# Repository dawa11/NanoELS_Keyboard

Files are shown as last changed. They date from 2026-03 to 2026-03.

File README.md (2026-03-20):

# Custom Mechanical Keyboard for NanoELS H5

## 1. Project Overview

This project provides the design and instructions to build a custom mechanical keyboard specifically tailored for the **NanoELS H5**. The NanoELS H5 is an advanced Electronic Lead Screw (ELS) system.

For more information on the NanoELS H5, please visit the official documentation and source code:
[https://github.com/kachurovskiy/nanoels/tree/main/h5](https://github.com/kachurovskiy/nanoels/tree/main/h5)

This keyboard combines all the essential keys documented for the H5 onto a simple, robust switchplate using mechanical switches, providing tactile feedback and a dedicated interface for operating your machine.

Photo of the finished Switchplate

---

## 2. Bill of Materials (BOM) & Requirements

To complete this build, you will need the following components and tools:

### Components
* **1x Microcontroller:** Must have at least **15 GPIO pins** and be **5V tolerant**.
    * *Recommended:* Arduino Micro or a compatible clone.
* **42x Mechanical Keyboard Switches:** Cherry MX style or clones.
* **Wiring/Cabling:** Thin hook-up wire.

### Tools & Equipment
* **Soldering Iron**
* **3D Printer**

---

## 3. 3D Printed Parts & Printing Guidelines

You have several options for the 3D printed parts, depending on your printer setup and aesthetic preferences.

### Options

#### Switchplate
* **Grooves:** Features visual separation grooves between the different key groups. Ideal for single-color prints.
* **Multi Material:** Has a flat surface modeled as a diferrent material between the key groups, designed for multi-color printing.

#### Keycaps
* **Embedded:** The key legends (labels) are modeled into the surface of the keycap. For single-color printing.
* **Multi Material:** Flat, the key legends are modeled as a diferrent material so they can be printed with two colors. Ideal for multi-color printing of the legends or manual labeling.

### Printing Requirements
* **Switchplate:** Can be printed with a standard **0.4mm nozzle**.
* **Keycaps:** To ensure the embedded or multi-color legends are legible, these **must** be printed with a finer **0.2mm nozzle** (hotend).

---

## 4. Wiring & Schematic

After fitting the 42 switches into the switchplate, they must be wired in a matrix configuration. The following schematic shows how to solder the switches to create a **7 row x 6 column switch matrix**.

Wire the Switches as shown in the Wiring Diagrams.
First the Rows of the Matrix.
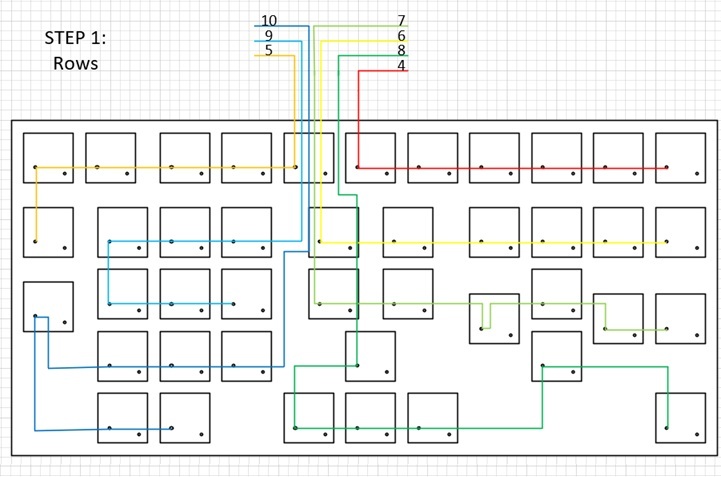
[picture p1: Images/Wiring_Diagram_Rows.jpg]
Wiring Diagram Rows


After that the Colums
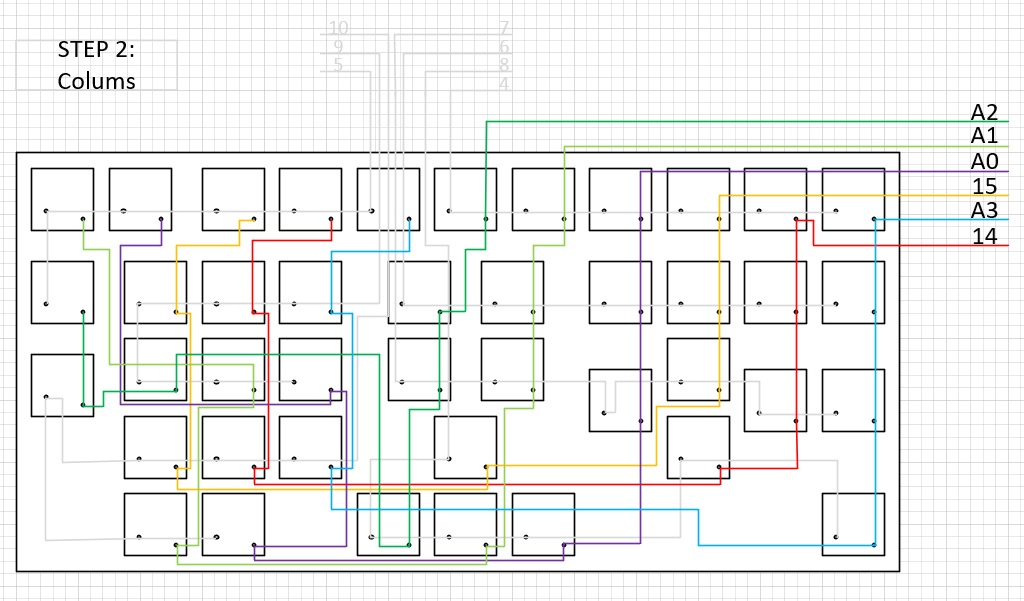
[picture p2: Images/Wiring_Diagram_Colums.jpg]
Wiring Diagram Rows


Finaly connect the wires to the specified PINs on the Microcontroller

This matrix is scanned by the microcontroller (e.g., Arduino Micro). The microcontroller translates the keypresses and sends the corresponding data to the NanoELS H5 controller via a **PS/2** interface.

### Controller Connection

To connect the keyboard to the NanoELS controller, use the following pinout:

| Arduino Pins | NanoELS PINS | Function |
| :--- | :--- | :--- |
| **VCC** | **5V** | Power Supply |
| **GND** | **GND** | Ground |
| **2** | **KEYC** | PS/2 Clock |
| **3** | **KEYD** | PS/2 Data |

---

## 5. Flashing the Controller

Download the Firmware **NanoELS-Keyboard.ino** from the Folder Source/NanoELS-Keyboard and FLash it to you Microcontroller with ArduinoIDE. After the flashing is completed you can open the Serial Monitor and look if the Arduino register every keypress.

---

## 6. Planned Improvements (Roadmap)

* **Handwheels:** Addition of mounting points for two incremental rotary encoders (handwheels) on the sides of the switchplate for precise X and Z axis control.

---

## 7. Known Bugs & Limitations

* **Unimplemented Keys:** The button corresponding to `Angle/RPM/Wifi` are currently non-functional.
* **STEP Buttons:** The `STEP +` and `STEP -` buttons currently perform the exact same function.
* **No Ghosting Protection:** The keyboard matrix does **not** include diodes. Pressing multiple keys simultaneously may lead to incorrect key detections ("ghosting"). **Only one key should be pressed at a time.**

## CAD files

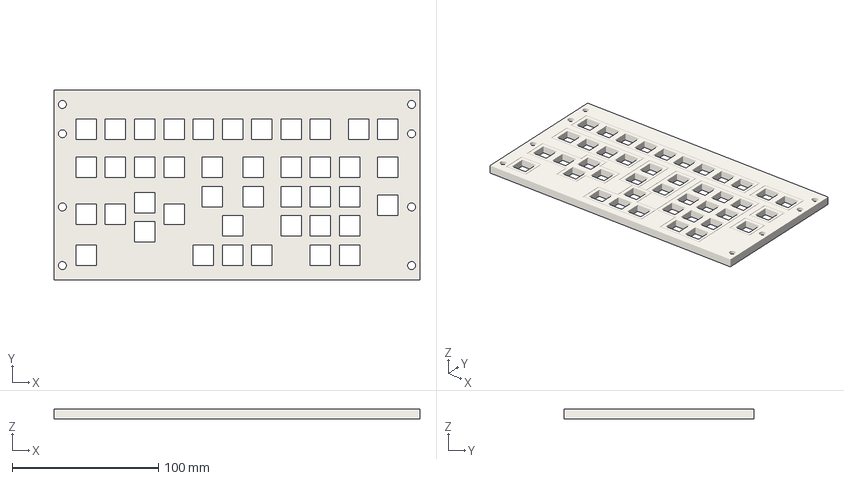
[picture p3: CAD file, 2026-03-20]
3D Files/Switchplate - grooves.3mf
250.0 x 130.0 x 7.00 mm

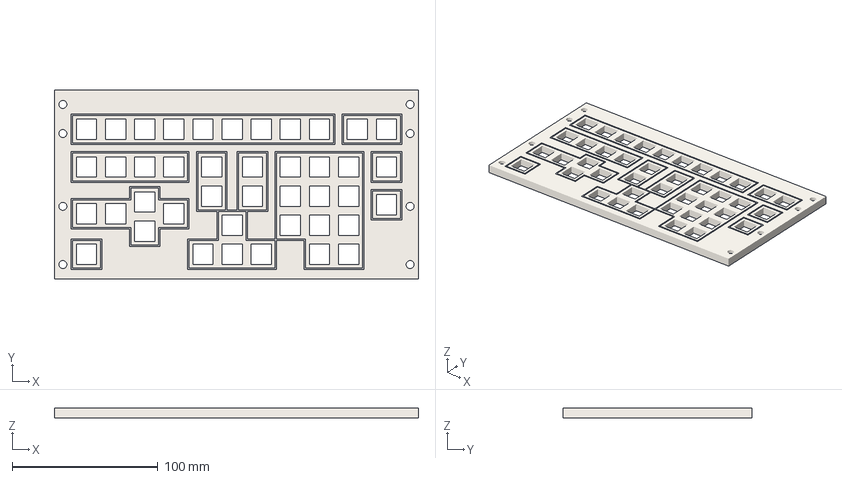
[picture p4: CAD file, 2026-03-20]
3D Files/Switchplate - Multi Material.3mf
250.0 x 130.0 x 7.00 mm
Körper1
Körper2
Körper3
Körper4
Körper5
Körper6
Körper7
Körper8
Körper9

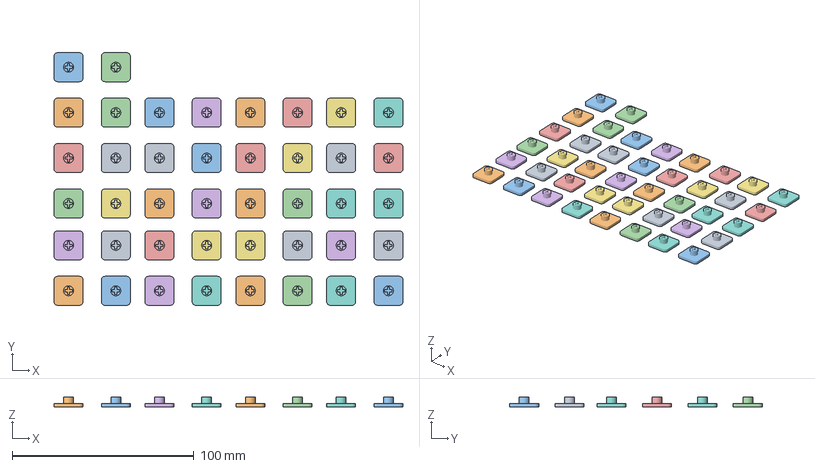
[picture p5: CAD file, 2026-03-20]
3D Files/Keycaps - embedded.3mf
192.0 x 139.0 x 5.60 mm
Körper10
Körper11
Körper12
Körper13
Körper14
Körper15
Körper16
Körper17
Körper18
Körper19
Körper2
Körper20
Körper21
Körper22
Körper23
Körper24
Körper25
Körper26
Körper27
Körper28
Körper29
Körper3
Körper30
Körper31
Körper32
Körper33
Körper34
Körper35
Körper36
Körper37
Körper38
Körper39
Körper4
Körper40
Körper41
Körper42
Körper5
Körper6
Körper7
Körper8
Körper9 x 2

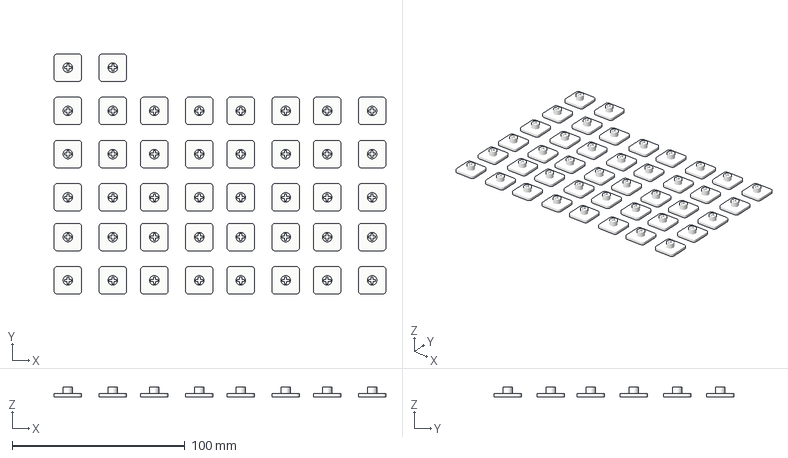
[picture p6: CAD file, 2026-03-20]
3D Files/Keycaps - Multi Material.3mf
192.0 x 139.0 x 5.60 mm
Körper1
Körper10
Körper100
Körper101
Körper102
Körper103
Körper104
Körper105
Körper106
Körper107
Körper108
Körper109
Körper11
Körper110
Körper111
Körper112
Körper113
Körper114
Körper115
Körper116
Körper117
Körper118
Körper119
Körper12
Körper120
Körper121
Körper122
Körper123
Körper124
Körper125
Körper126
Körper127
Körper128
Körper129
Körper13
Körper130
Körper131
Körper132
Körper133
Körper134
Körper135
Körper136
Körper137
Körper138
Körper139
Körper14
Körper140
Körper141
Körper142
Körper143
Körper144
Körper145
Körper146
Körper147
Körper148
Körper149
Körper15
Körper150
Körper151
Körper152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

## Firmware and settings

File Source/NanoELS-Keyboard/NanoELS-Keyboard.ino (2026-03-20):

#include <Keypad.h>
#include <ps2dev.h>

// PS/2 Pins: Clock an Pin 2, Data an Pin 3
PS2dev keyboard(2, 3);

const byte ROWS = 7; 
const byte COLS = 6; 

// Definition der Pins
byte rowPins[ROWS] = {4, 5, 6, 7, 8, 9, 10}; 
byte colPins[COLS] = {A3, 14, 15, A0, A1, A2}; 

// Tasten-Indizes für die Matrix
char keys[ROWS][COLS] = {
  {'q', 'w', 'e', 'r', 't', 'z'},   //F1, F2, F3, F4, F5, F6
  {'u', 'i', 'o', 'p', 'a', 'R'},   //F7, F8, F9, Enter, ESC, R
  {'Q', 'A', 'Z', 'D', '`', '+'},   //Q, A, Z, D, `, +
  {'C', 'S', 'X', 'W', '~', '-'},   //C, S, X, W, ~, -
  {'s', 'O', 'f', 'h', 'g', 'j'},   //Win, O, Up-Arrow, Left-Arrow, Down Arrow~, Right-Arrow
  {'7', '8', '9', '4', '5', '6'},   //7, 8, 9, 4, 5, 6
  {'1', '2', '3', '0', 'd', 'M'}    //1, 2, 3, 0, Backspace, M
};

Keypad keypad = Keypad(makeKeymap(keys), rowPins, colPins, ROWS, COLS);

void setup() {
  keyboard.keyboard_init();
  Serial.begin(9600);
}

// Zentrale Funktion zum Senden der PS/2 Befehle (Set 2)
void sendPS2(uint16_t scancode, bool pressed) {
  if (pressed) {
    if (scancode > 0xFF) keyboard.write(0xE0); // Extended-Präfix
    keyboard.write(scancode & 0xFF);           // Make-Code
  } else {
    if (scancode > 0xFF) keyboard.write(0xE0); // Extended-Präfix
    keyboard.write(0xF0);                      // Break-Code Präfix
    keyboard.write(scancode & 0xFF);           // Key-Code
  }
}

void loop() {
  // keypad.getKeys() füllt eine interne Liste mit allen Tasten, 
  // deren Status sich geändert hat.
  if (keypad.getKeys()) {
    // Wir nutzen hier 10 als Sicherheit (maximale Anzahl gleichzeitig erkannter Tasten)
    for (int i=0; i<10; i++) { 
      if (keypad.key[i].stateChanged) {
        bool isPressed = (keypad.key[i].kstate == PRESSED || keypad.key[i].kstate == HOLD);
        processKey(keypad.key[i].kchar, isPressed);
      }
    }
  }
}

void processKey(char key, bool pressed) {
  switch (key) {
    // Buchstaben
    case 'A': sendPS2(0x1C, pressed); Serial.println("A"); break;
    case 'W': sendPS2(0x1D, pressed); Serial.println("W"); break;
    case 'S': sendPS2(0x1B, pressed); Serial.println("S"); break;
    case 'D': sendPS2(0x23, pressed); Serial.println("D"); break;
    case 'R': sendPS2(0x2D, pressed); Serial.println("R"); break;
    case 'M': sendPS2(0x3A, pressed); Serial.println("M"); break;
    case 'X': sendPS2(0x22, pressed); Serial.println("X"); break;
    case 'Z': sendPS2(0x1A, pressed); Serial.println("Z"); break;
    case 'C': sendPS2(0x21, pressed); Serial.println("C"); break;
    case 'Q': sendPS2(0x15, pressed); Serial.println("Q"); break;
    case 'O': sendPS2(0x44, pressed); Serial.println("O"); break;

    // F-Tasten
    case 'q': sendPS2(0x05, pressed); Serial.println("F1"); break; // F1
    case 'w': sendPS2(0x06, pressed); Serial.println("F2"); break; // F2
    case 'e': sendPS2(0x04, pressed); Serial.println("F3"); break; // F3
    case 'r': sendPS2(0x0C, pressed); Serial.println("F4"); break; // F4
    case 't': sendPS2(0x03, pressed); Serial.println("F5"); break; // F5
    case 'z': sendPS2(0x0B, pressed); Serial.println("F6"); break; // F6
    case 'u': sendPS2(0x83, pressed); Serial.println("F7"); break; // F7
    case 'i': sendPS2(0x0A, pressed); Serial.println("F8"); break; // F8
    case 'o': sendPS2(0x01, pressed); Serial.println("F9"); break; // F9
    
    // Zahlen (Hauptreihe)
    case '0': sendPS2(0x45, pressed); Serial.println("0"); break;
    case '1': sendPS2(0x16, pressed); Serial.println("1"); break;
    case '2': sendPS2(0x1E, pressed); Serial.println("2"); break;
    case '3': sendPS2(0x26, pressed); Serial.println("3"); break;
    case '4': sendPS2(0x25, pressed); Serial.println("4"); break;
    case '5': sendPS2(0x2E, pressed); Serial.println("5"); break;
    case '6': sendPS2(0x36, pressed); Serial.println("6"); break;
    case '7': sendPS2(0x3D, pressed); Serial.println("7"); break;
    case '8': sendPS2(0x3E, pressed); Serial.println("8"); break;
    case '9': sendPS2(0x46, pressed); Serial.println("9"); break;

    // Sonderzeichen & System
    case '+': sendPS2(0x12, pressed); sendPS2(0x55, pressed); Serial.println("+"); break; // Numpad +
    case '-': sendPS2(0x4E, pressed); Serial.println("-"); break; // Numpad -
    case 'p': sendPS2(0x5A, pressed); Serial.println("Enter"); break; // Enter
    case 'a': sendPS2(0x76, pressed); Serial.println("ESC"); break; // Escape
    case 'd': sendPS2(0x66, pressed); Serial.println("Backspace"); break; // Backspace
    case 's': sendPS2(0x00, pressed); Serial.println("Windows"); break; // Windows Taste
    case '~': sendPS2(0x12, pressed); sendPS2(0x0E, pressed); Serial.println("Tilde"); break; //Tilde
    case '`': sendPS2(0x0E, pressed); Serial.println("Backtick"); break; //Backtick

    // Pfeiltasten (Extended)
    case 'f': sendPS2(0xE075, pressed); Serial.println("Up"); break; // Hoch
    case 'g': sendPS2(0xE072, pressed); Serial.println("Down"); break; // Runter
    case 'h': sendPS2(0xE06B, pressed); Serial.println("Left"); break; // Links
    case 'j': sendPS2(0xE074, pressed); Serial.println("Right"); break; // Rechts
  }
}

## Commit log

2026-03-20 Added 3D Files
    [Switchplate - Multi Material.stl, Switchplate - detented.stl]
2026-03-20 renamed 3D files to Match Readme
    [Switchplate - embedded.stl]
2026-03-20 Updated 3D Files
    [Keycaps - Multi Material.3mf, Keycaps - embedded.3mf, Switchplate - Multi Material.3mf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]
2026-03-20 Fix image link for finished switchplate photo
2026-03-20 Fix image link for finished switchplate in README
2026-03-20 Rename Finished Switchplate.jpg to Finished-Switchplate.jpg
2026-03-20 Added Image of Finished Switchplate
2026-03-20 Added Wiring Diagrams
2026-03-20 Enhance wiring section with diagrams and instructions
    Updated wiring instructions and added diagrams for clarity.
2026-03-20 New Wiring Diagramm Image
2026-03-20 Fix spelling errors in README wiring instructions
    Corrected spelling errors in the wiring instructions.
